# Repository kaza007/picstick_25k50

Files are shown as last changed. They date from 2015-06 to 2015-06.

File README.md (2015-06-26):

# picstick_25k50
PIC18F25K50 Pinguino compatible USB stick

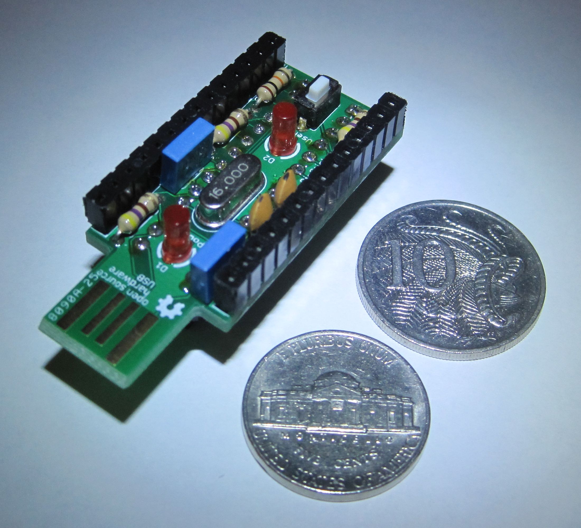
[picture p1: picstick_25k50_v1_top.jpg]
Top View


Background
------------

The picstick_25k50 is a small PCB that can be connected directly into a USB connector. It is based on the [LeoStick (Arduino Compatible)](http://www.freetronics.com.au/products/leostick#.VWqnws-qpHw) form factor and the hardware is identical to the [PIC18F45K50 Pinguino](http://wiki.pinguino.cc/index.php/PIC18F45K50_Pinguino) except that the 28pin PIC is used instead of the 40pin.

The picstick_25k50 was created to add to the ever growing choice of PIC alternatives to Arduino. There are no surface mount components, so the picstick_25k50 is easy to build.

Pinout
-------

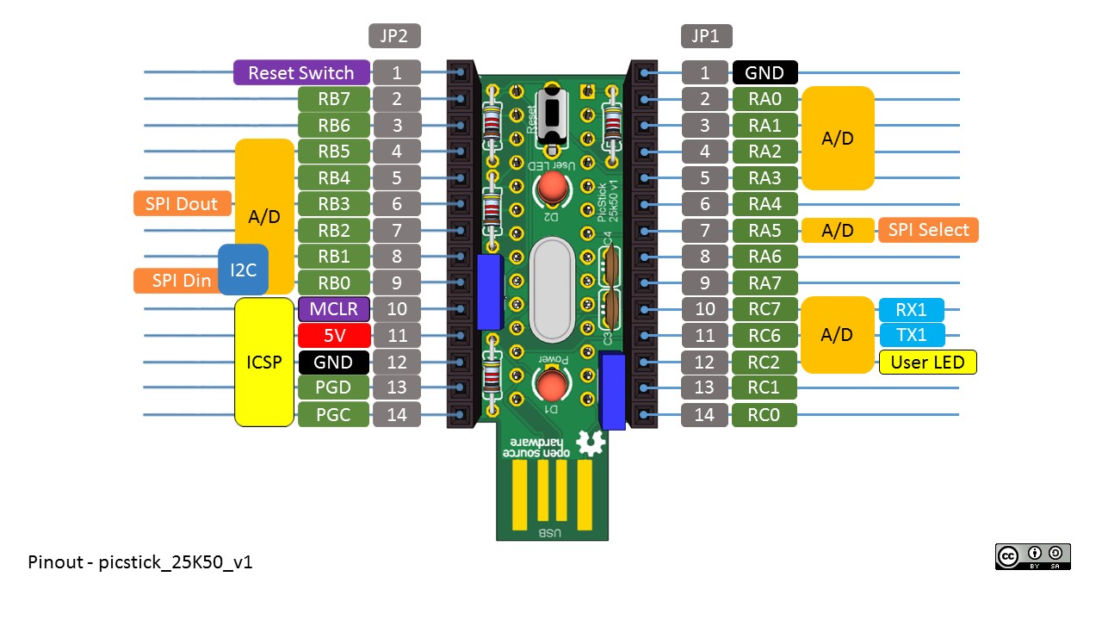
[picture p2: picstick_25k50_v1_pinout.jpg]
Pinout


[Construction](https://github.com/kaza007/picstick_25k50/blob/master/construction)
--------------

[Schematic](https://github.com/kaza007/picstick_25k50/blob/master/picstick_25k50_v1.sch.png)
----------

PIC Bootloader
-----------------
The PIC18F25K50 must be programmed with the Pinguino Bootloader as described in the Pinguino [Basics](http://wiki.pinguino.cc/index.php/Basics#Bootloader) page.

This project uses Bootloader_v4.14_18f25k50_INTOSC.hex.

Testing
-------
Blinking led test, blink.pde

##
	void setup()
	{  
		pinMode(USERLED, OUTPUT);
	}
 
	void loop()

	{
		toggle(USERLED);
		delay(500);
	}

Design Software
-----------------
This project was designed with [Eagle](http://www.cadsoftusa.com/) 7.2.0, [Sketchup](http://www.sketchup.com/) 15.3.331 and [EagleUp](http://eagleup.wordpress.com) 4.5.

License
-------


This work is licensed under a [Creative Commons Attribution-ShareAlike 4.0 International License](<http://creativecommons.org/licenses/by-sa/4.0/).

Original design by: [Pinguino](http://www.pinguino.cc/).

Modified by: [*https://github.com/kaza007*](https://github.com/kaza007)

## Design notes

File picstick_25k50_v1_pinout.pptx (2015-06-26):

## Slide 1

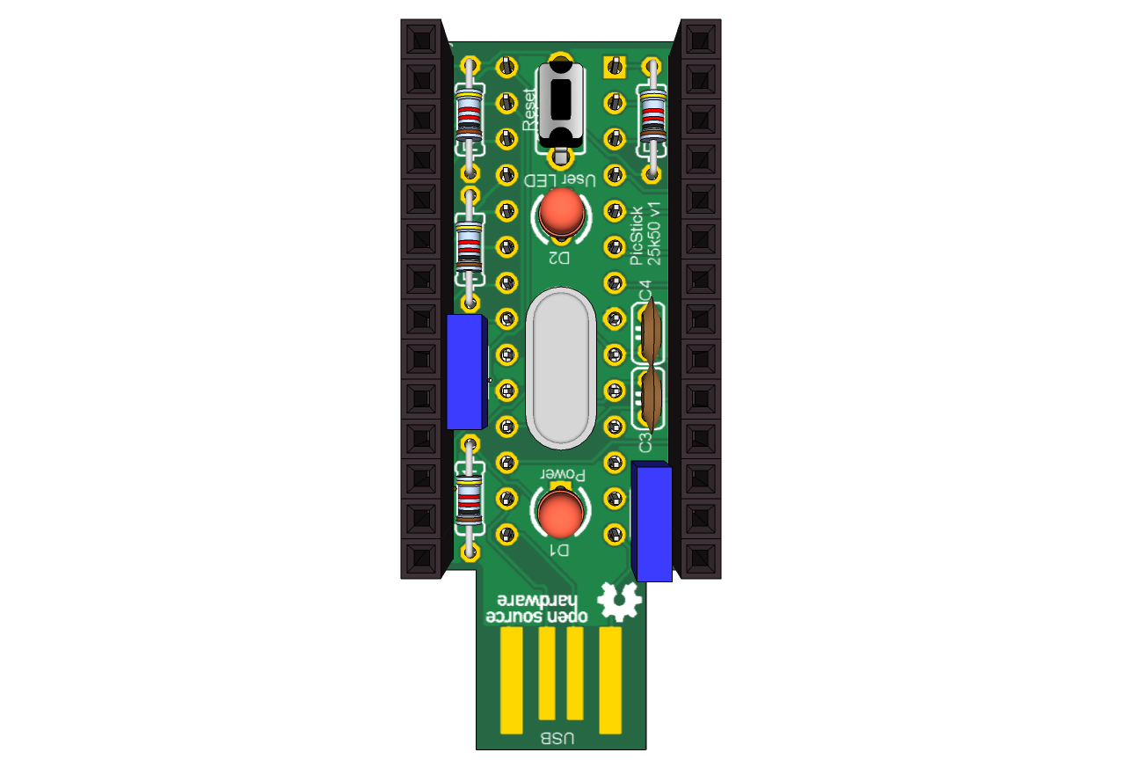
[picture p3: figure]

JP2

JP1

Reset Switch

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
ICSP

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
SPI Dout

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
SPI Select

SPI Din

RB0

MCLR

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
User LED

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
Pinout - picstick_25K50_v1

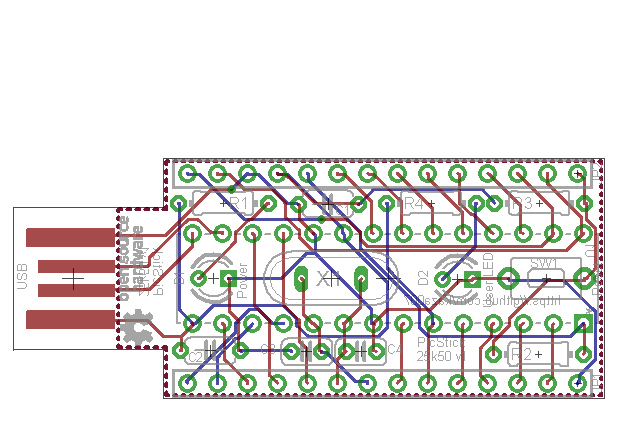
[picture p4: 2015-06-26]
picstick_25k50_v1.brd.png

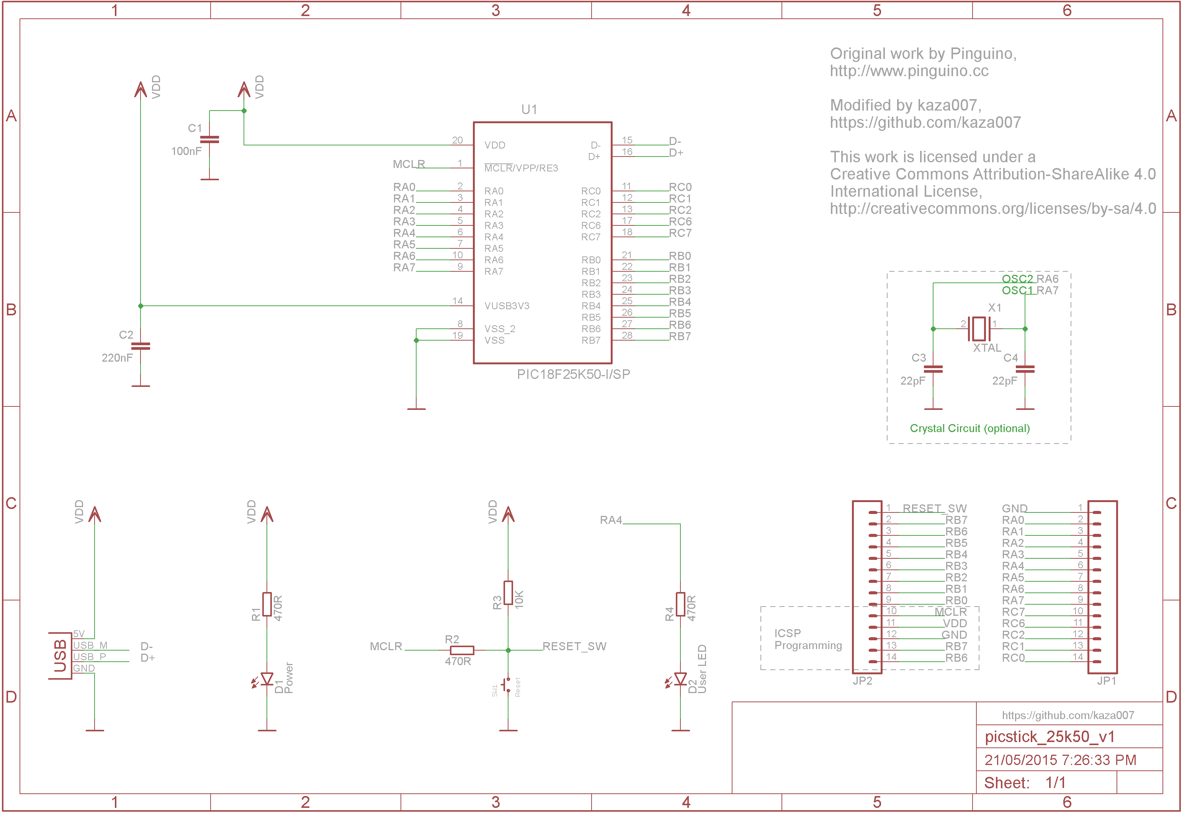
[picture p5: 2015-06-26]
picstick_25k50_v1.sch.png

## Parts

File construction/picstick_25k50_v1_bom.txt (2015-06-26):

Qty	Value	Device	Package	Parts	Description	Digi-Key Part #	Description	Manufacturer Part #	Element14 #
2	Header	FREETRONICS-JON_M14	FREETRONICS-JON_1X14	"JP1, JP2"	Connector Header 14 Position	S7012-ND	"RECEPTACLE, 2.54MM, SINGLE, 14WAY"	CES-114-01-T-S	1667519
1	100nF	C-EU050-024X044	C025-024X044	C1	CAPACITOR	495-2481-ND	CAPACITOR POLYESTER FILM 0.1UF 100V 10%	B32529C1104K	2098447
1	10K	R-EU_0204/7	0204/7	R3	RESISTOR	10KQBK-ND	"RESISTOR, CARBON , 10K, 0.33W, 5%"	CFR25J10K	2329609
3	470R	R-EU_0204/7	0204/7	"R1, R2, R4"	RESISTOR	470QBK-ND	"RESISTOR, CARBON , 470R, 0.33W, 5%"	CFR25J470R	2329680
2	"Pwr, User LED"	LED3MM	LED3MM	"D1, D2"	LED	160-1139-ND	"LED, 3MM, RED, 13MCD, 635NM"	MCL284MD	2365815
1	Reset	SKHLAAA010	SKHLAAA010	SW1	SWITCH	679-2452-ND	"SWITCH, TACT, MOM, 5MM"	FSMH	1813688
2	SIP Socket	IC SOCKET	x		Connector Socket 14 Position	1212-1101-ND	"SOCKET, SIL, 20WAY"	D01-9972042	1023034
1	PIC18F25K50-I/SP	PIC18F25K50-I/SP	DIP254P762X406-28P	U1	IC MCU 8BIT 32KB FLASH 28SDIP	PIC18F25K50-I/SP-ND	"MCU, 8BIT, PIC18, 48MHZ, SPDIP-28"	PIC18F25K50-I/SP	2305832
1	220nF	C-EU050-024X044	C050-024X044	C2	CAP FILM 0.22UF 10% 63VDC RADIAL	B32529C0224K000	"CAP, FILM, PET, 220NF, 63V, RAD"	B32529C0224K000	9750894
									
Optional components									
2	22pF	C-EU025-024X044	RCL_C025-024X044	"C3, C4"	CAPACITOR	BC1005CT-ND	"CERAMIC CAPACITOR 22PF 50V, C0G/NP0, 5%, RADIAL"	MCCC50V220JNPO	1600966
1	XTAL	XTAL/S	QS	X1	Crystal 16.0000MHz 30ppm 20pF 40 Ohm -40°C - 85°C Through Hole HC49/US	CTX1084-ND	"CRYSTAL, HC-49/S, 16.0MHZ"	HC49S-16-30-50-70-30-ATF	1667003

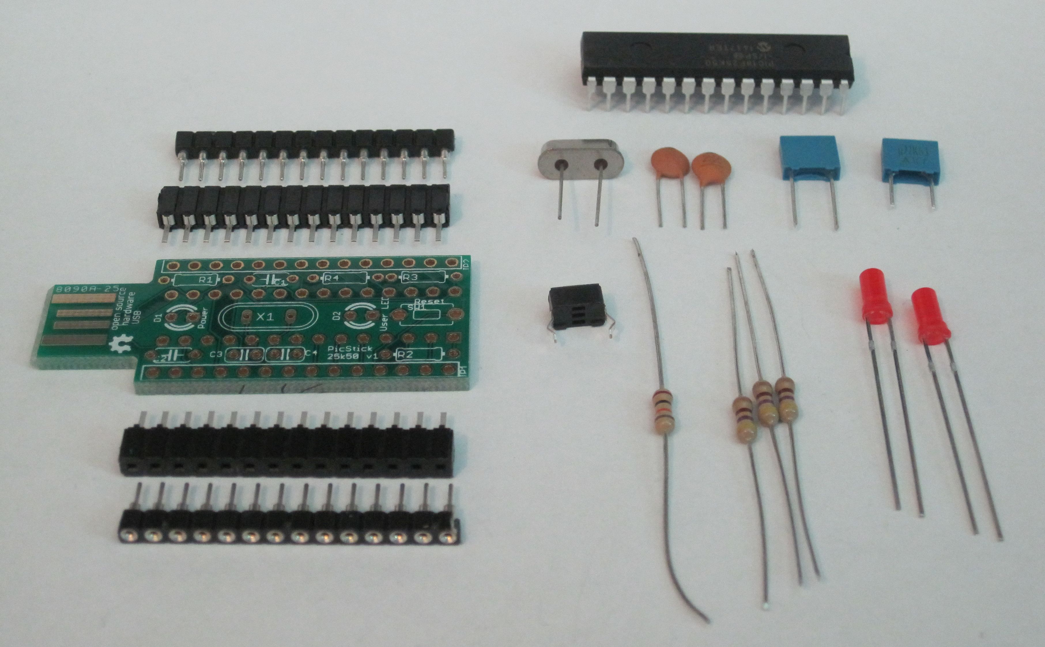
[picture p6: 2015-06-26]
construction/picstick_25k50_v1_components.jpg

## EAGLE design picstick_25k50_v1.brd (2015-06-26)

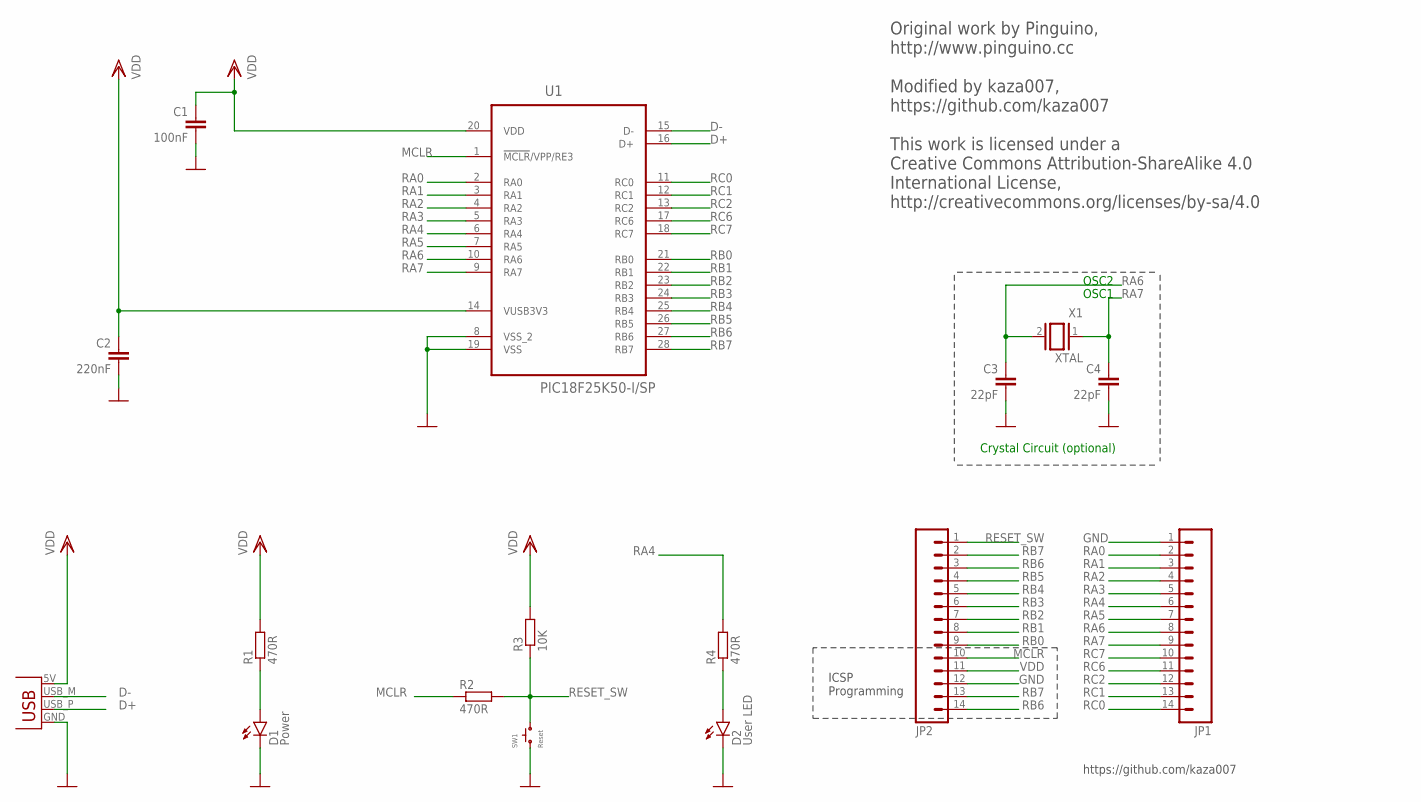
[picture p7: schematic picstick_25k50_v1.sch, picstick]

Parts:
C1: 100nF; C050-024X044
C2: 220nF; C050-024X044
C3, C4: 22pF; C025-024X044
D1: Power; LED3MM
D2: User LED; LED3MM
JP1, JP2: FREETRONICS-JON_M14; FREETRONICS-JON_1X14
R1, R2, R4: 470R; 0204/7
R3: 10K; 0204/7
SW1: Reset; SKHLAAA010
U1: PIC18F25K50-I/SP; DIP254P762X406-28P
USB: FREETRONICS-MASTER-V1_USBPCB; FREETRONICS-MASTER-V1_USB-A-PCB
X1: XTAL; QS

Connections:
D+: U1.16 (D+), USB.USB_P (D+)
D-: U1.15 (D-), USB.USB_M (D-)
GND: C1.2, C2.2, C3.2, C4.2, D1.K (C), D2.K (C), JP1.1, JP2.12, SW1.1, U1.8 (VSS_2), U1.19 (VSS), USB.GND
MCLR: JP2.10, R2.1, U1.1 (!MCLR!/VPP/RE3)
unnamed: D1.A, R1.1
unnamed: D2.A, R4.1
RA0: JP1.2, U1.2 (RA0)
RA1: JP1.3, U1.3 (RA1)
RA2: JP1.4, U1.4 (RA2)
RA3: JP1.5, U1.5 (RA3)
RA4: JP1.6, R4.2, U1.6 (RA4)
RA5: JP1.7, U1.7 (RA5)
RA6: C3.1, JP1.8, U1.10 (RA6), X1.2
RA7: C4.1, JP1.9, U1.9 (RA7), X1.1
RB0: JP2.9, U1.21 (RB0)
RB1: JP2.8, U1.22 (RB1)
RB2: JP2.7, U1.23 (RB2)
RB3: JP2.6, U1.24 (RB3)
RB4: JP2.5, U1.25 (RB4)
RB5: JP2.4, U1.26 (RB5)
RB6: JP2.3, JP2.14, U1.27 (RB6)
RB7: JP2.2, JP2.13, U1.28 (RB7)
RC0: JP1.14, U1.11 (RC0)
RC1: JP1.13, U1.12 (RC1)
RC2: JP1.12, U1.13 (RC2)
RC6: JP1.11, U1.17 (RC6)
RC7: JP1.10, U1.18 (RC7)
RESET_SW: JP2.1, R2.2, R3.1, SW1.2
VDD: C1.1, C2.1, JP2.11, R1.2, R3.2, U1.14 (VUSB3V3), U1.20 (VDD), USB.5V (VBUS)

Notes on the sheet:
ICSP Programming
Crystal Circuit (optional)
OSC2
OSC1
https://github.com/kaza007
Original work by Pinguino, http://www.pinguino.cc Modified by kaza007, https://github.com/kaza007 This work is licensed under a Creative Commons Attribution-ShareAlike 4.0 International License, http://creativecommons.org/licenses/by-sa/4.0

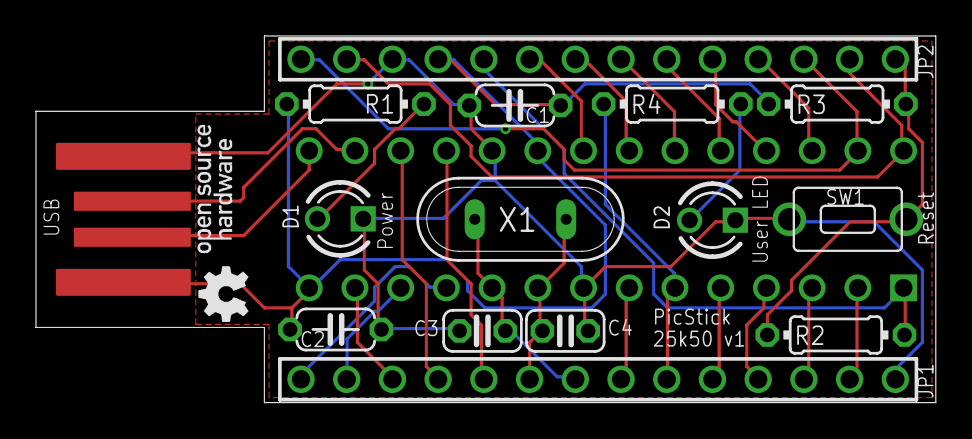
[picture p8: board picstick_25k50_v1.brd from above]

Board: 2 copper layers, 50.0 x 20.4 mm, 16 parts (1 on the bottom side), 29 nets.

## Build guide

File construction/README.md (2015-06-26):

# picstick_25k50
PIC18F25K50 Pinguino compatible USB stick

Construction
------------

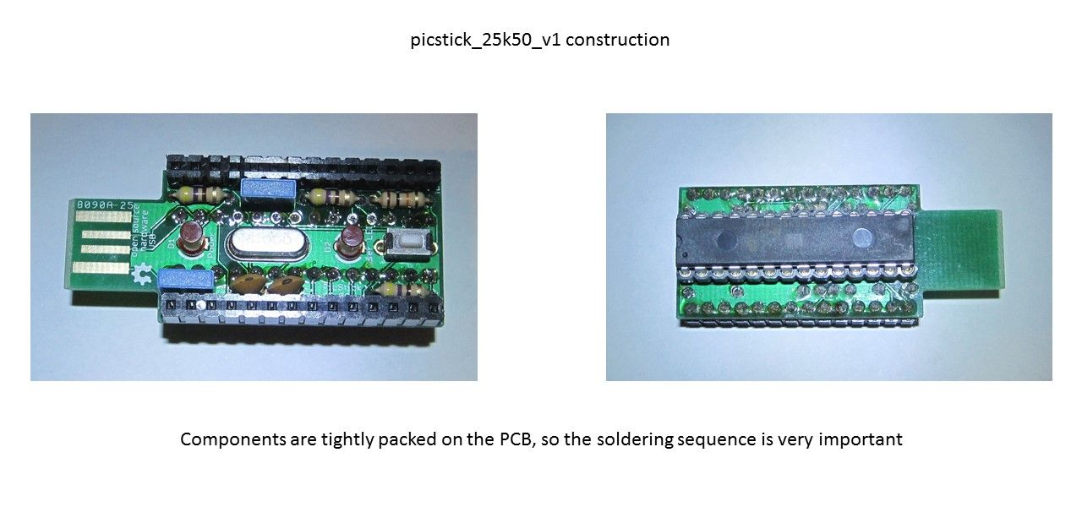
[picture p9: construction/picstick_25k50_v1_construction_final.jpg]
Completed PCB


[Components](https://github.com/kaza007/picstick_25k50/blob/master/construction/picstick_25k50_v1_components.jpg) are to be placed and soldered in the following order to make construction as easy as possible. 

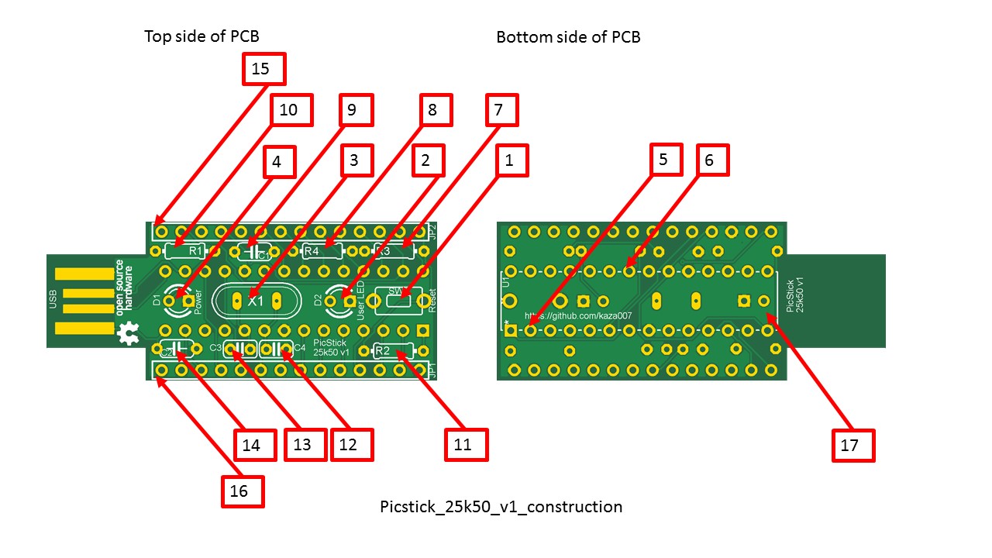
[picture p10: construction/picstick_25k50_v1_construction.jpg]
PartsOrder


Follow the image for the order of placement where each number corresponds to the instruction below.

For components that are not polarised, place them so that you can still read their markings. Resistors can be placed with colour codes reading left to right.

1. Place SW1, switch on the top side of the PCB. It does not matter in which direction it is placed. Solder.
2. Place D2, Red LED on the top side of the PCB. The LED is a polarised part so the long lead must face the X1 crystal. Solder and trim the leads.
3. Optional. Place X1, 16MHz crystal on the top side of the PCB.  It does not matter in which direction it is placed. Solder and trim the leads.
4. Place D1, Red LED on the top side of the PCB. The LED is a polarised part so the long lead must face the USB connector. Solder and trim the leads.
5. Place one side of the pin-header connectors for U1 on the bottom side of the PCB. Solder.
6. Place the other side of the pin-header connectors for U1 on the bottom side of the PCB. Solder.
7. Place R3, 10K resistor on the top side of the PCB. It does not matter in which direction it is placed. Solder and trim the leads.
8. Place R4, 470R resistor on the top side of the PCB. It does not matter in which direction it is placed. Solder and trim the leads.
9. Place C1, 100nF capacitor on the top side of the PCB. It does not matter in which direction it is placed. Solder and trim the leads.
10. Place R1, 470R resistor on the top side of the PCB. It does not matter in which direction it is placed. Solder and trim the leads.
11. Place R2, 470R resistor on the top side of the PCB. It does not matter in which direction it is placed. Solder and trim the leads.
12. Optional. Place C4, 22pF capacitor on the top side of the PCB. It does not matter in which direction it is placed. Solder and trim the leads.
13. Optional. Place C3, 22pF capacitor on the top side of the PCB. It does not matter in which direction it is placed. Solder and trim the leads.
14. Place C2, 220nF capacitor on the top side of the PCB. It does not matter in which direction it is placed. Solder and trim the leads.
15. Place JP2, 14 way pin header on the top side of the PCB. Solder the leads.
16. Place JP1, 14 way pin header on the top side of the PCB. Solder the leads.
17. Place U1, the PIC18F25k50 microcontroller in its socket on the bottom side of the PCB. This will be easier if you first bend the two rows of pins a little bit in towards each other. Note that the microcontroller chip has a notch at one end. This notch must be at the end where the U1 is on the PCB silkscreen.
